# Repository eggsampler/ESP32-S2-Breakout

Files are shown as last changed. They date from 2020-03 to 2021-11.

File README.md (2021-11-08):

# ESP32-S2-Breakout

**May 2021:** New v2 boards [assembled with USB-C connector](https://cdn.discordapp.com/attachments/743434443859034135/847350110374461490/image0.jpg), tested and working well over USB CDC-ACM and DFU programming.

**Feb 2021:** Updated to v2, switched from micro usb to usb-c connector, minor routing changes. PCB ordered, updates to come.

**July 2020:** Board has been [assembled](https://i.imgur.com/Ixv2GHa.jpg), but not fully tested. Currently waiting for ESP-IDF release with full s2 support.

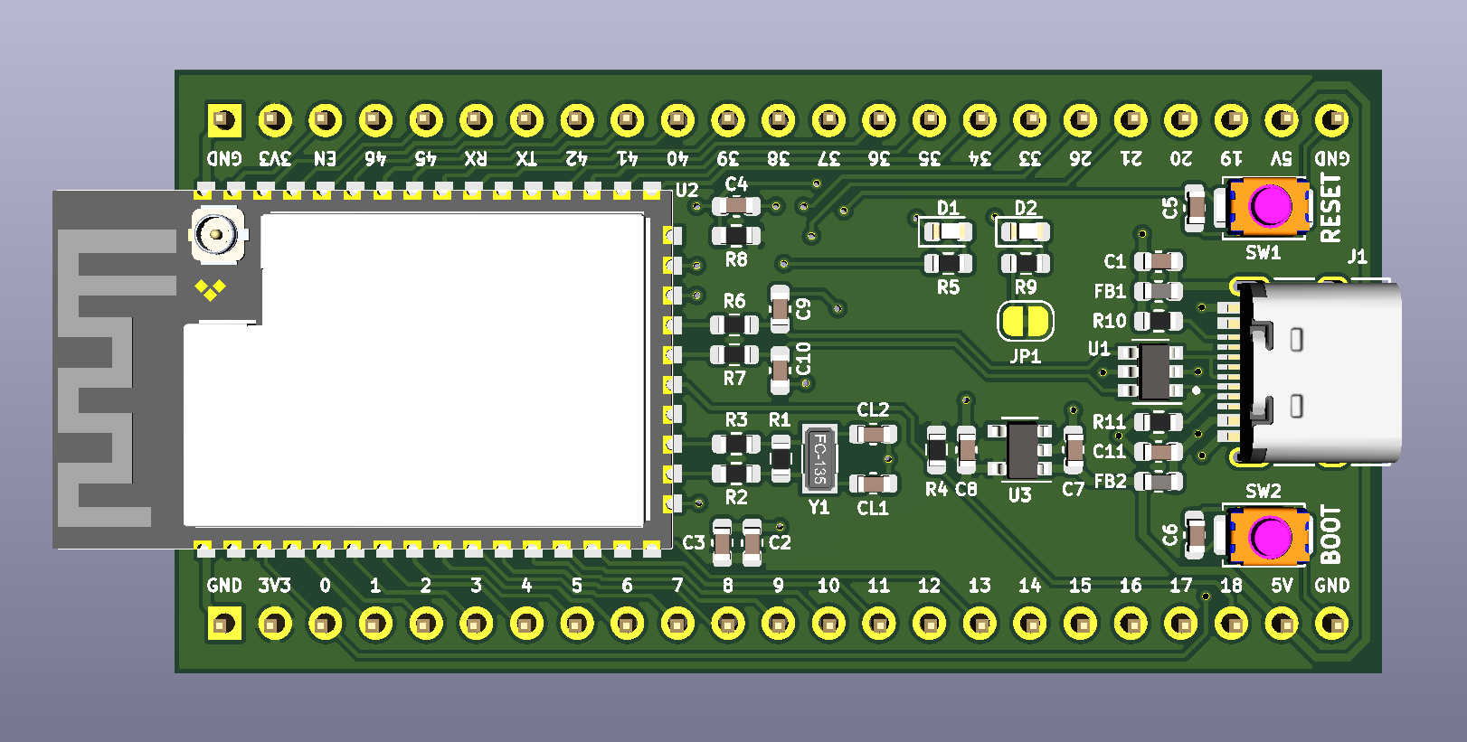
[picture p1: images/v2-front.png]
ESP32-S2-Breakout


This board is a minimal breakout board for the new ESP32-S2-WROOM module from [Espressif](https://www.espressif.com/). It was designed with a few criteria in mind,

- Breakout as many pins as possible, if not all, from the module
- Be relatively easy for a hobbyist to order & assemble
- Use a minimal amount of components

To that end, a few choices were made,

- Designed in [KiCad](https://kicad.org/) to be accessible to most people
- Use as little active components as possible
  - Note, it is definitely possible to use less than is currently laid out and the design will (slowly) be iterated on towards this.
- Using 0603 (imperial) sized passives
  - Ideally the board would be constructed using solder paste, a stencil and either some form of reflow oven or hot plate (even a [skillet on a stove](https://www.sparkfun.com/tutorials/59) is fine)
- To have the boards cheaply manufactured by most turn-key pcb fab houses,
  - Power traces should be at least 12 mil
  - Signal traces should be at least 8 mil
  - Vias should be 0.3mm drill size with a 0.6mm pad size
- No LGA parts, and ideally no QFN parts

## Initial Design

The initial design was taken from the [ESP32-S2-WROOM & ESP32-S2-WROOM-I Datasheet](https://www.espressif.com/sites/default/files/documentation/esp32-s2-wroom_esp32-s2-wroom-i_datasheet_en.pdf) (v0.5) section *6. Peripheral Schematics* Figure 5.

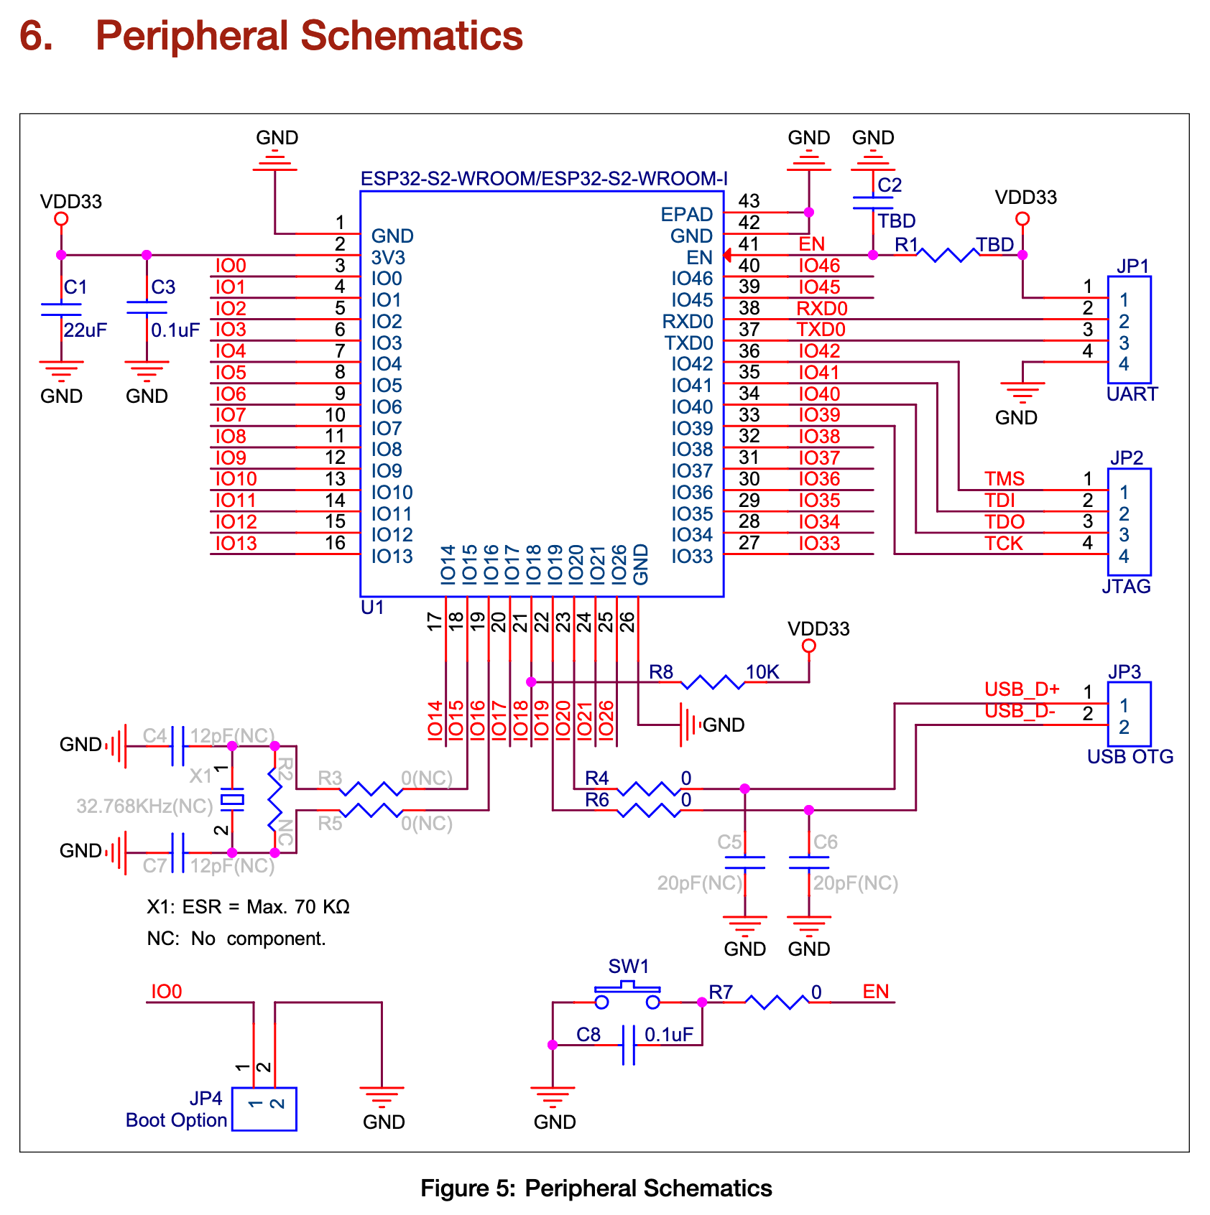
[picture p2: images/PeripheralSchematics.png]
Peripheral Schematics


A few changes were made from this schematic.

- The USB data lines were directed to a USB-C connector
- 22 ohm termination resistors are used on the USB data lines, along with including the 20pF caps
- No 0 resistor was used on the EN reset switch, just tied directly to the EN pin
- A switch was also used on IO0 for the boot mode, instead of a connector/header
- No separate connectors for UART/JTAG, all pins were broken out to 2.54mm/0.1" headers

## Component Selection

### 1. 3v3 Regulator

A regulator which has high efficiencies (ie, low ground/quiescent current) is needed to get the best out of powering the device from higher voltages. The XC6220 has a hysterisis mode called "Green Operation" where the supply current current is much lower when the load current is below 2mA. The v1 of this board will also be a bit of a test for this regulator to see how it handles higher loads for wifi, and lower loads for sleep modes.

### 2. 32.768 KHz Crystal

A few resources were useful when researching crystal and component choices.

1. https://en.wikipedia.org/wiki/Pierce_oscillator
2. http://ww1.microchip.com/downloads/en/AppNotes/00943A.pdf
3. http://www.crystek.com/documents/appnotes/Pierce-GateIntroduction.pdf
4. http://www.st.com/internet/com/TECHNICAL_RESOURCES/TECHNICAL_LITERATURE/APPLICATION_NOTE/CD00221665.pdf

A cheap crystal FC-135 with a max ESR of 70kOhms was used which fits on the KiCad 3215 pad. A few passive values will need to be tested for v1 to determine if they're even necessary.

### 3. Switches / Connectors

The switches and connectors were chosen because they had footprints already in the KiCad library and are relatively accessible from most vendors.

### 4. USB ESD Protection

A USBLC6-2SC6 was chosen for ESD protection of the USB power and data lines. This part was already available in KiCad and at a few distributors. An input capacitor was used fort this part, along with a ferrite bead before the 5v bus.

Another ferrite bead and capacitor was used between the shield and the ground. Probably not strictly necessary.

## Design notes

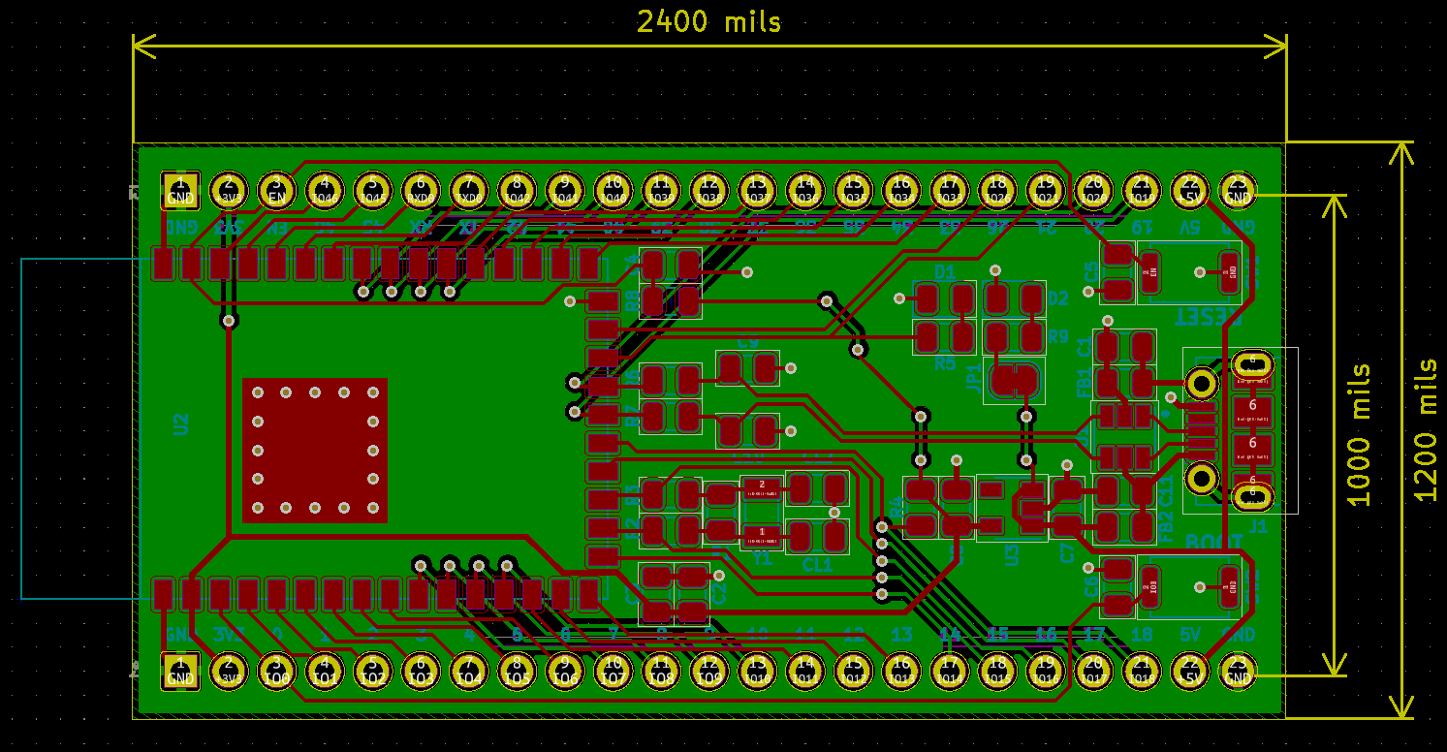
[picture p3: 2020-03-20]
images/v1-pcb.PNG

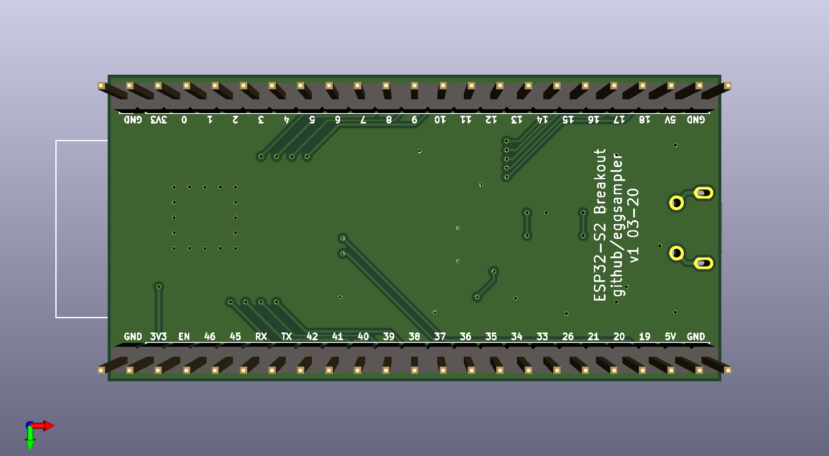
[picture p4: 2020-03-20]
images/v1-back.png

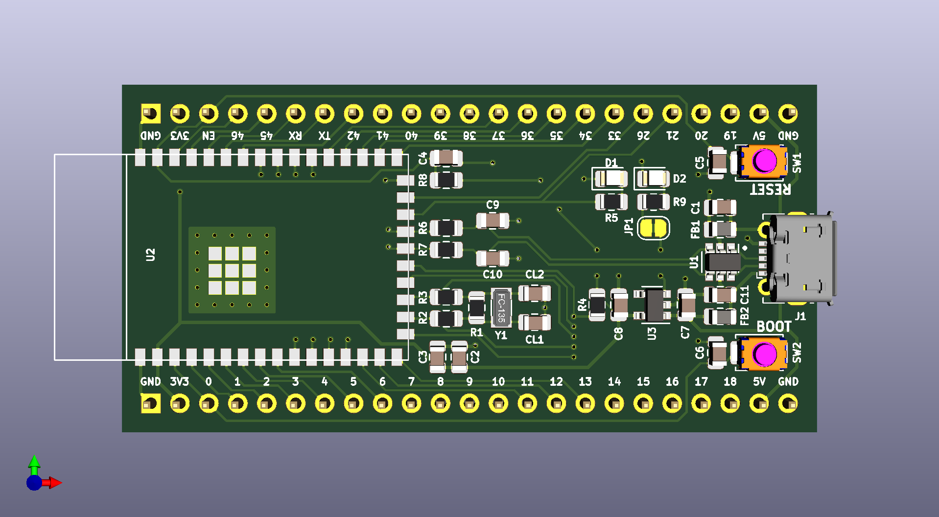
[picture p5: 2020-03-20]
images/v1-front.png

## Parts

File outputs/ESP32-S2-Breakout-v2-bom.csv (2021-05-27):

Qty | Reference(s) | Value | Footprint | LCSC
6 | C1, C3, C4, C5, C6, C11 | 0.1u X7R 50V | C_0603_1608Metric | C14663
1 | C2 | 22u X5R 10V | C_0603_1608Metric | C59461
1 | C7 | 10u X5R 16V | C_0603_1608Metric | C19702
1 | C8 | 4.7u X5R 25V | C_0603_1608Metric | C19666
4 | C9, C10, CL1, CL2 | 20p C0G 50V | C_0603_1608Metric | C1648
1 | D1 | LED 2.8V 5mA Red | LED_0603_1608Metric | C2286
1 | D2 | LED 2.8V 5mA Green | LED_0603_1608Metric | C72043
2 | FB1, FB2 | >1A | L_0603_1608Metric | C85831
1 | J1 | USB_C_Receptacle_USB2.0 | HRO_TYPE-C-31-M-12 | C165948
1 | R1 | N/C | R_0603_1608Metric | -
2 | R2, R3 | 0r | R_0603_1608Metric | C21189
2 | R4, R8 | 10k 5% | R_0603_1608Metric | C25804
2 | R5, R9 | 100r 1% | R_0603_1608Metric | C22775
2 | R6, R7 | 22r 1% | R_0603_1608Metric | C23345
2 | R10, R11 | 5.1k 5% | R_0603_1608Metric | C23186
1 | SW1 | Reset | Alps_SKRK | C115357
1 | SW2 | Boot | Alps_SKRK | C115357
1 | U1 | USBLC6-2SC6 | SOT-23-6 | C558442
1 | U2 | ESP32-S2-WROVER | ESP32-S2-WROVER | C701327
1 | U3 | XC6220B331MR | SOT-23-5 | C86534
1 | Y1 | 32.768KHz 12.5pF 70kR | Crystal_SMD_3215 | C32346

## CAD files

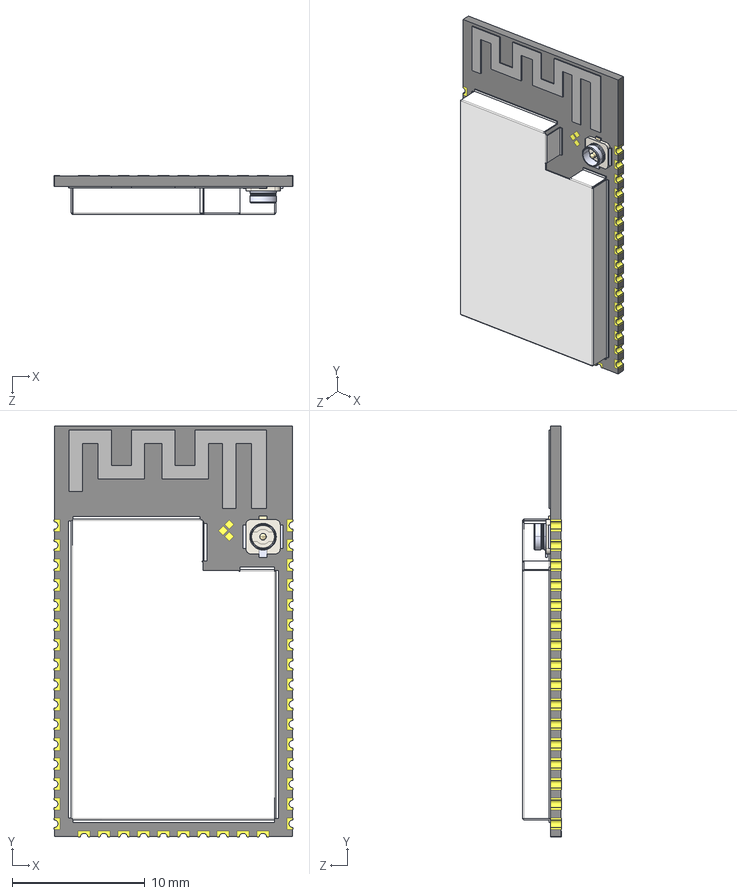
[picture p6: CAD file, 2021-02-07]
ESP32-S2-Breakout/3d/ESP32-S2-WROVER.STEP
18.0 x 31.0 x 2.91 mm

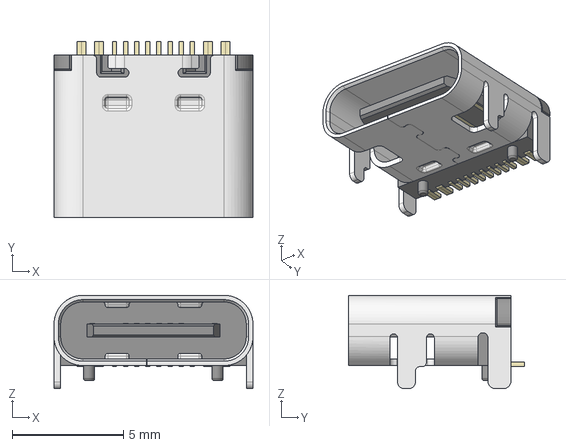
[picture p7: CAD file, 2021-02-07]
ESP32-S2-Breakout/3d/HRO_TYPE-C-31-M-12.step
8.95 x 7.90 x 4.20 mm

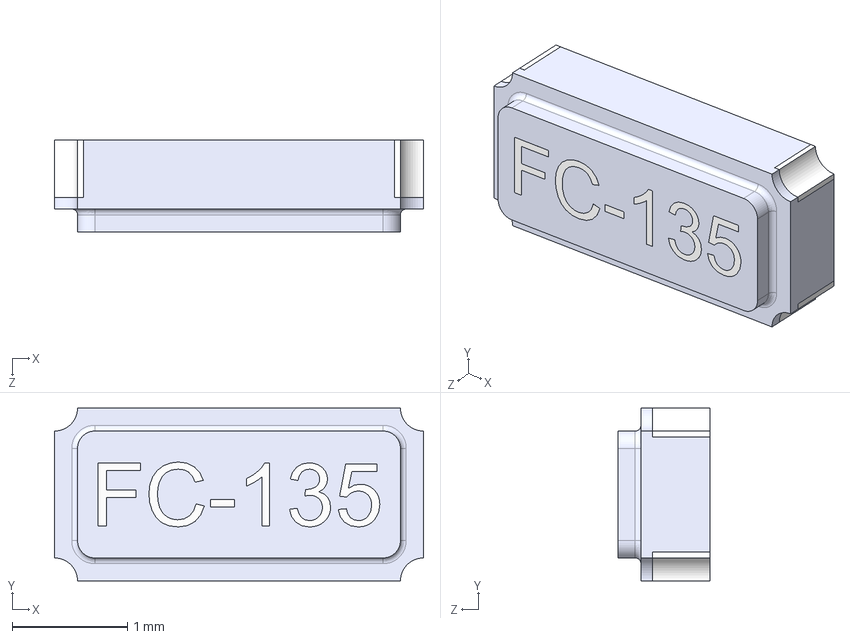
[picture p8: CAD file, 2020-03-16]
ESP32-S2-Breakout/3d/FC-135.STEP
3.20 x 1.50 x 0.8 mm
Pin 2
Pin 1
Tekst Inlay

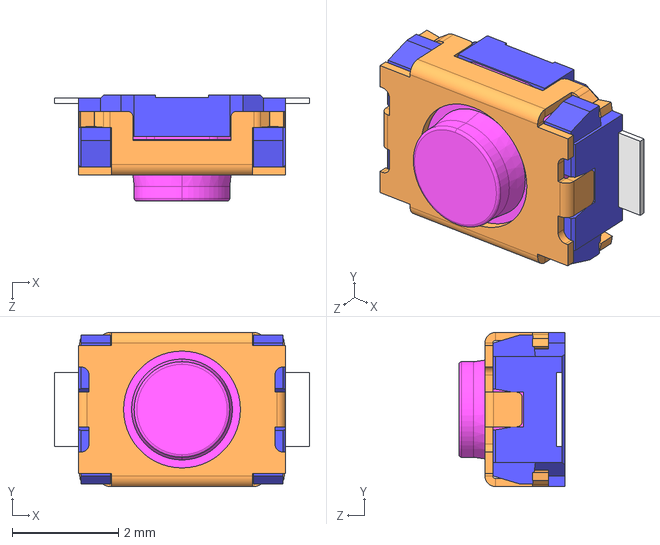
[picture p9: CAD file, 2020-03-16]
ESP32-S2-Breakout/3d/SKRKAH.STEP
4.80 x 2.90 x 2.00 mm

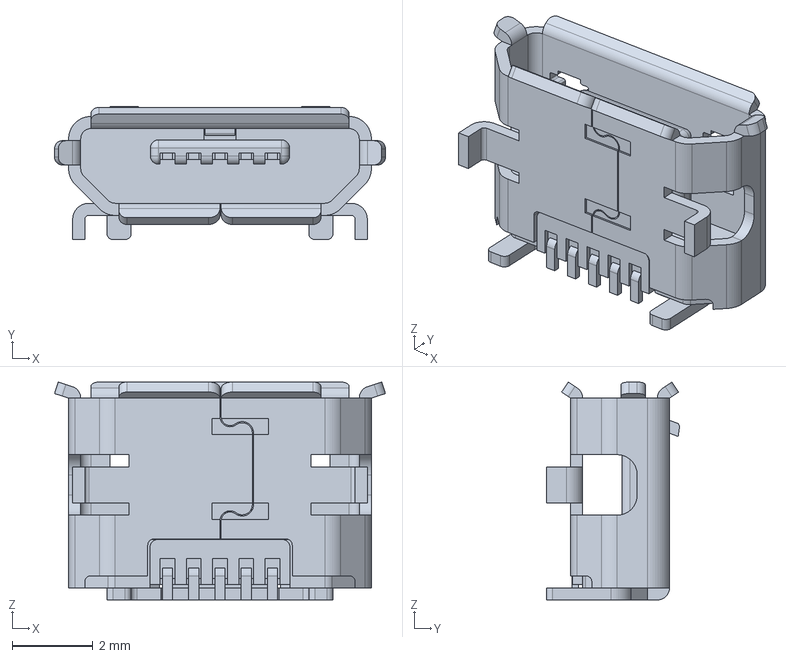
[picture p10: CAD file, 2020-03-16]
ESP32-S2-Breakout/3d/1050170001.stp
8.20 x 3.30 x 5.40 mm

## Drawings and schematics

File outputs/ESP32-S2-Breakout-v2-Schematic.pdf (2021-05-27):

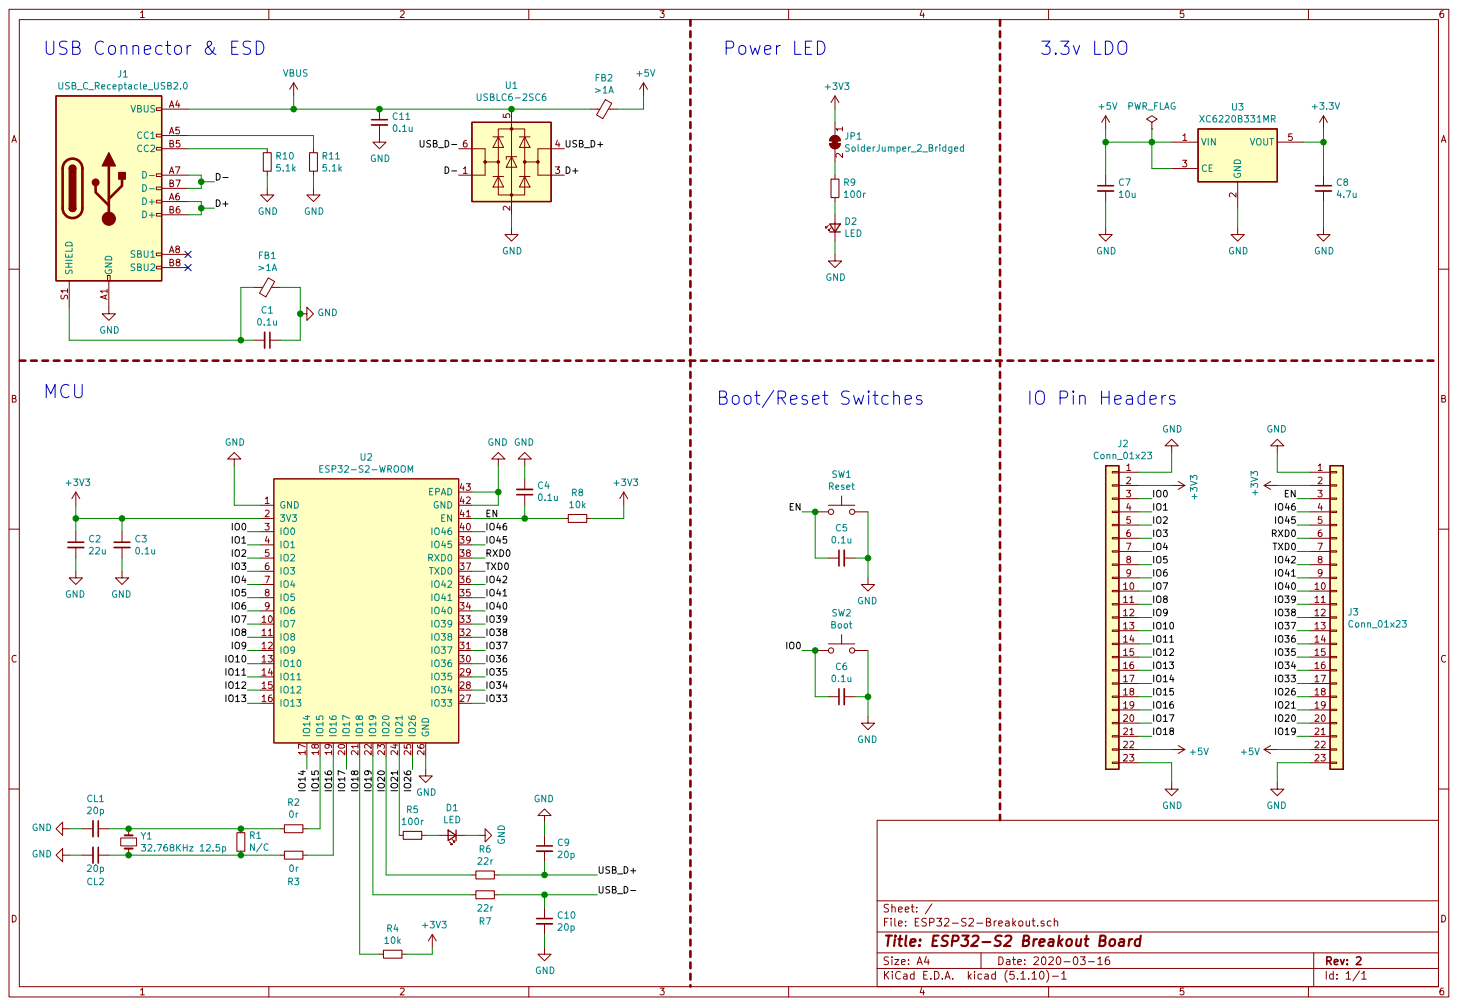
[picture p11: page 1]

File: ESP32-S2-Breakout.sch Sheet: /
Id: 1/1 Title: ESP32-S2 Breakout Board

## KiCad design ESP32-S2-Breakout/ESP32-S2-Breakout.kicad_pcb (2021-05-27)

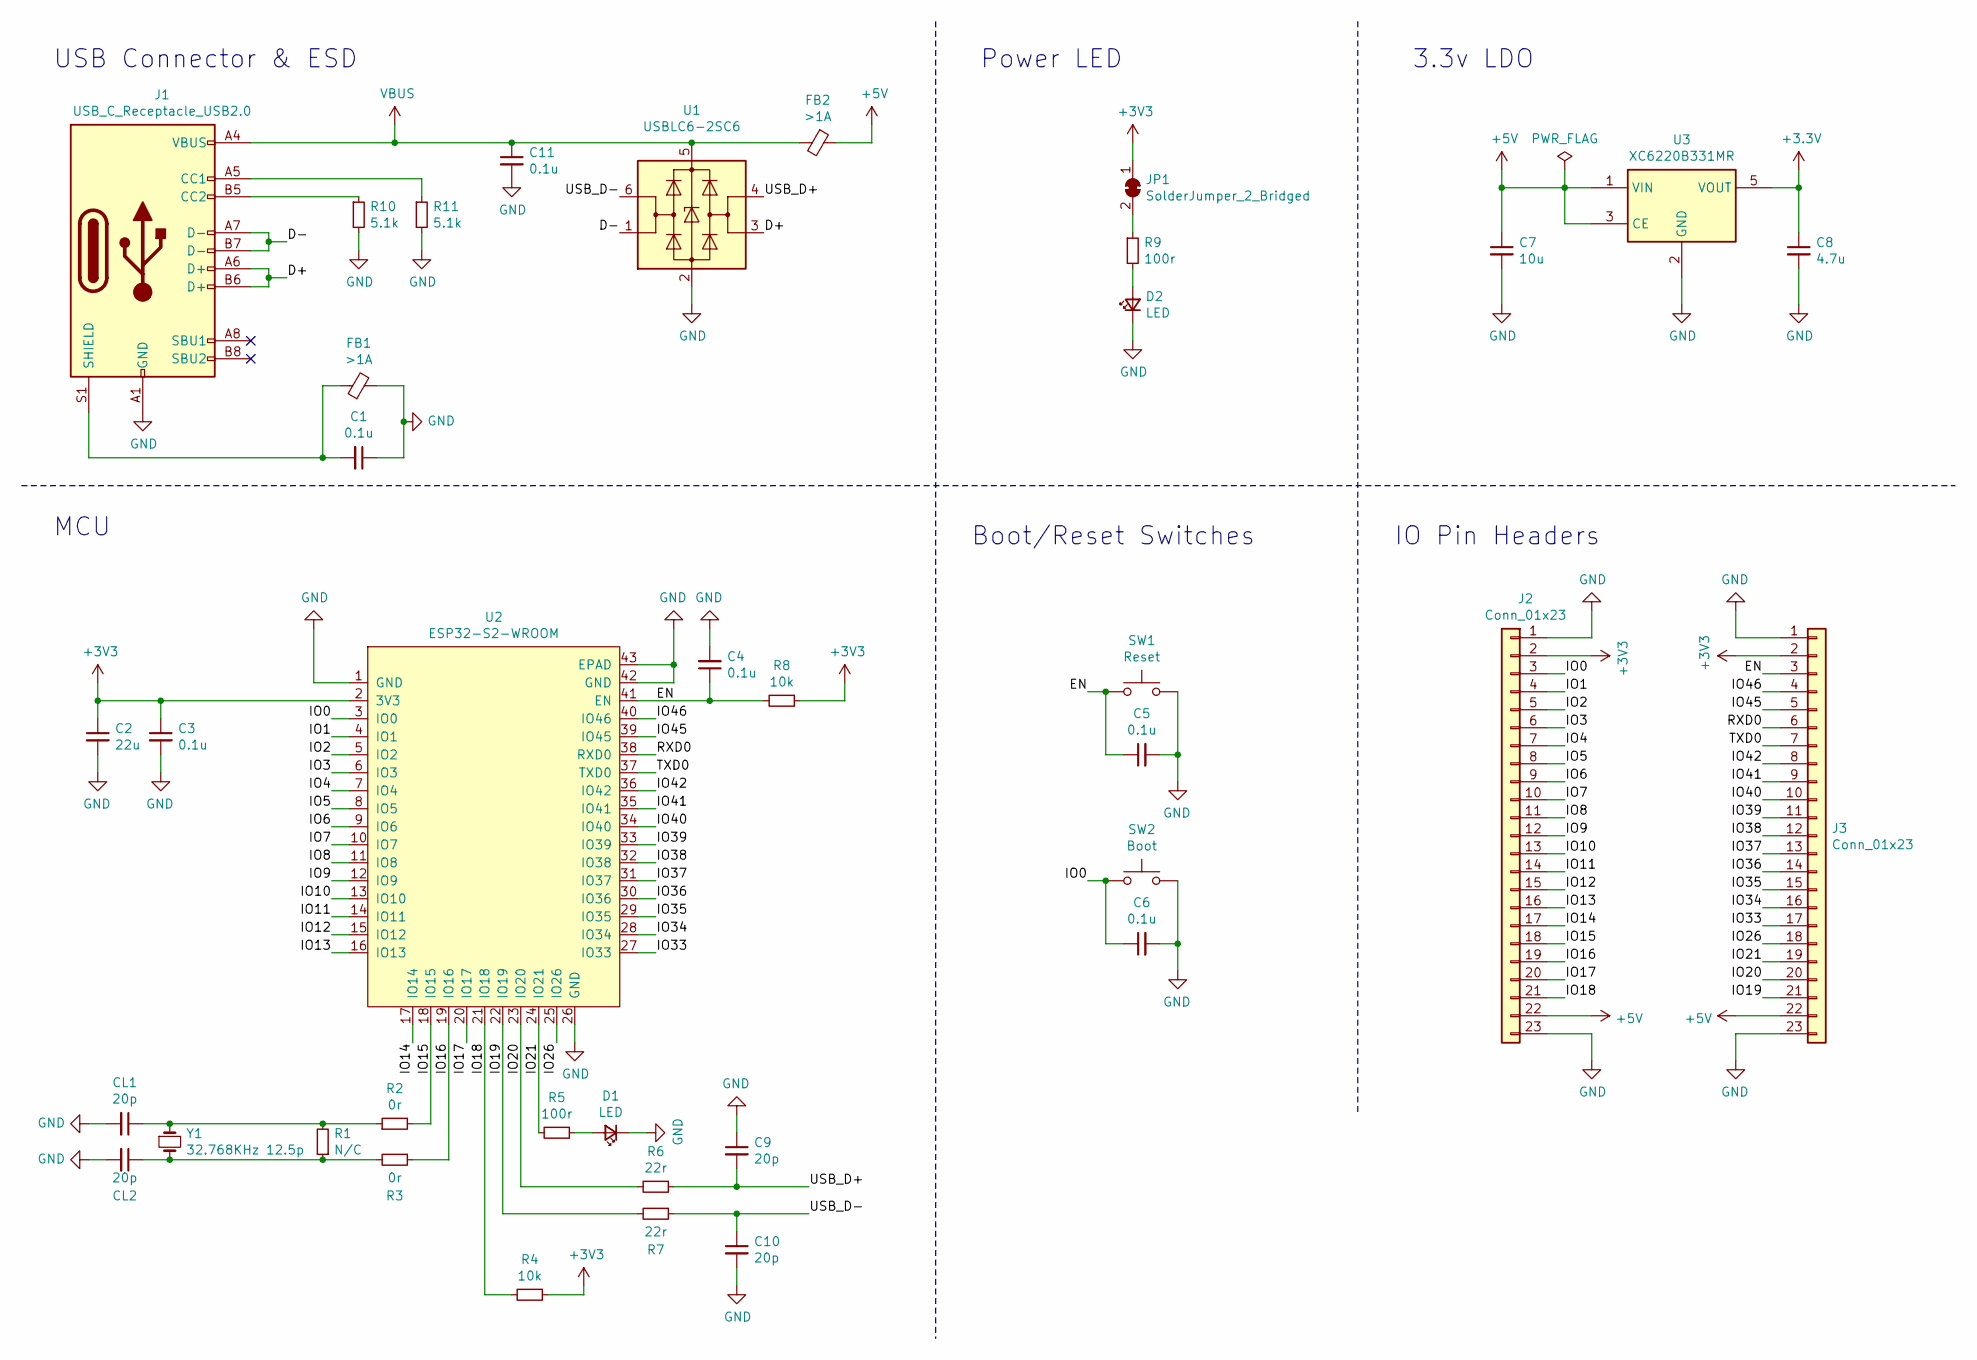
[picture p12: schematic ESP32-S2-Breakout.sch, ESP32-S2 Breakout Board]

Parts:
C1, C3, C4, C5, C6, C11: 0.1u; C_0603_1608Metric; LCSC C14663
C2: 22u; C_0603_1608Metric; LCSC C84419
C7: 10u; C_0603_1608Metric; LCSC C90058
C8: 4.7u; C_0603_1608Metric; LCSC C69335
C9, C10: 20p; C_0603_1608Metric; LCSC C1648
CL1, CL2: 20p; C_0603_1608Metric; LCSC C1648
D1: LED; LED_0603_1608Metric; LCSC C205443
D2: LED; LED_0603_1608Metric; LCSC C205445
FB1, FB2: >1A; L_0603_1608Metric; LCSC C24821
J1: USB_C_Receptacle_USB2.0; USB_C_Receptacle_HRO_TYPE-C-31-M-12; LCSC C165948
J2, J3: Conn_01x23; PinHeader_1x23_P2.54mm_Vertical
JP1: SolderJumper_2_Bridged; SolderJumper-2_P1.3mm_Bridged_RoundedPad1.0x1.5mm
R1: N/C; R_0603_1608Metric
R2, R3: 0r; R_0603_1608Metric; LCSC C21189
R4, R8: 10k; R_0603_1608Metric; LCSC C99198
R5, R9: 100r; R_0603_1608Metric; LCSC C22775
R6, R7: 22r; R_0603_1608Metric; LCSC C23345
R10, R11: 5.1k; R_0603_1608Metric; LCSC C163928
SW1: Reset; Alps_SKRK; LCSC C115357
SW2: Boot; Alps_SKRK; LCSC C115357
U1: USBLC6-2SC6; SOT-23-6; LCSC C7519
U2: ESP32-S2-WROOM; LCSC C701327
U3: XC6220B331MR; SOT-23-5; LCSC C86534
Y1: 32.768KHz 12.5p; Crystal_SMD_3215-2Pin_3.2x1.5mm; LCSC C271654

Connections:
+5V: C7.1, FB2.1, J2.22, J3.22, U3.1 (VIN), U3.3 (CE)
/D+: J1.A6 (D+), J1.B6 (D+), U1.3 (I/O2)
/D-: J1.A7 (D-), J1.B7 (D-), U1.1 (I/O1)
/EN: C4.1, C5.1, J3.3, R8.2, SW1.2, U2.41 (EN)
/IO0: C6.1, J2.3, SW2.2, U2.3 (IO0)
/IO1: J2.4, U2.4 (IO1)
/IO2: J2.5, U2.5 (IO2)
/IO3: J2.6, U2.6 (IO3)
/IO4: J2.7, U2.7 (IO4)
/IO5: J2.8, U2.8 (IO5)
/IO6: J2.9, U2.9 (IO6)
/IO7: J2.10, U2.10 (IO7)
/IO8: J2.11, U2.11 (IO8)
/IO9: J2.12, U2.12 (IO9)
/IO10: J2.13, U2.13 (IO10)
/IO11: J2.14, U2.14 (IO11)
/IO12: J2.15, U2.15 (IO12)
/IO13: J2.16, U2.16 (IO13)
/IO14: J2.17, U2.17 (IO14)
/IO15: J2.18, R2.2, U2.18 (IO15)
/IO16: J2.19, R3.1, U2.19 (IO16)
/IO17: J2.20, U2.20 (IO17)
/IO18: J2.21, R4.2, U2.21 (IO18)
/IO19: J3.21, R7.2, U2.22 (IO19)
/IO20: J3.20, R6.2, U2.23 (IO20)
/IO21: J3.19, R5.2, U2.24 (IO21)
/IO26: J3.18, U2.25 (IO26)
/IO33: J3.17, U2.27 (IO33)
/IO34: J3.16, U2.28 (IO34)
/IO35: J3.15, U2.29 (IO35)
/IO36: J3.14, U2.30 (IO36)
/IO37: J3.13, U2.31 (IO37)
/IO38: J3.12, U2.32 (IO38)
/IO39: J3.11, U2.33 (IO39)
/IO40: J3.10, U2.34 (IO40)
/IO41: J3.9, U2.35 (IO41)
/IO42: J3.8, U2.36 (IO42)
/IO45: J3.5, U2.39 (IO45)
/IO46: J3.4, U2.40 (IO46)
/RXD0: J3.6, U2.38 (RXD0)
/TXD0: J3.7, U2.37 (TXD0)
/USB_D+: C9.2, R6.1, U1.4 (I/O2)
/USB_D-: C10.1, R7.1, U1.6 (I/O1)
GND: C1.1, C2.2, C3.2, C4.2, C5.2, C6.2, C7.2, C8.2, C9.1, C10.2, C11.2, CL1.2, CL2.2, D1.1 (K), D2.1 (K), FB1.2, J1.A1 (GND), J1.A12 (GND), J1.B1 (GND), J1.B12 (GND), J2.1, J2.23, J3.1, J3.23, R10.2, R11.2, SW1.1, SW2.1, U1.2 (GND), U2.1 (GND), U2.26 (GND), U2.42 (GND), U2.43 (EPAD), U3.2 (GND)
unnamed: C1.2, FB1.1, J1.S1 (SHIELD)
unnamed: CL1.1, R1.2, R2.1, Y1.1
unnamed: CL2.1, R1.1, R3.2, Y1.2
unnamed: D1.2 (A), R5.1
unnamed: D2.2 (A), R9.2
unnamed: J1.A5 (CC1), R11.1
unnamed: J1.B5 (CC2), R10.1
unnamed: JP1.2 (B), R9.1
VBUS: C11.1, FB2.2, J1.A4 (VBUS), J1.A9 (VBUS), J1.B4 (VBUS), J1.B9 (VBUS), U1.5 (VBUS)

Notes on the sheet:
USB Connector & ESD
Power LED
3.3v LDO
MCU
Boot/Reset Switches
IO Pin Headers

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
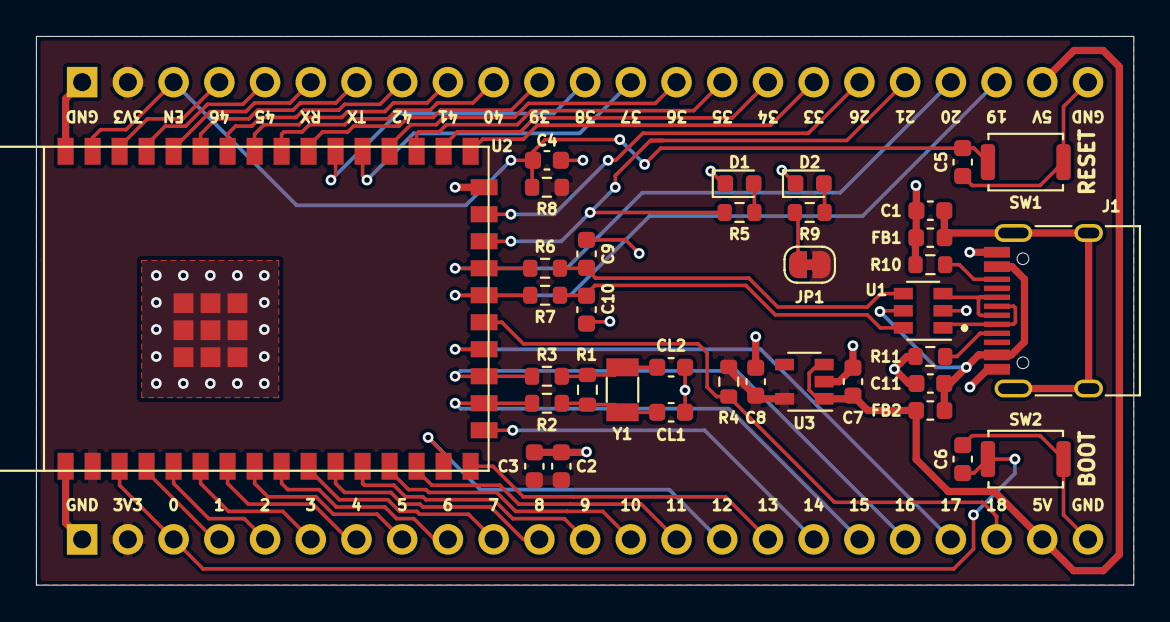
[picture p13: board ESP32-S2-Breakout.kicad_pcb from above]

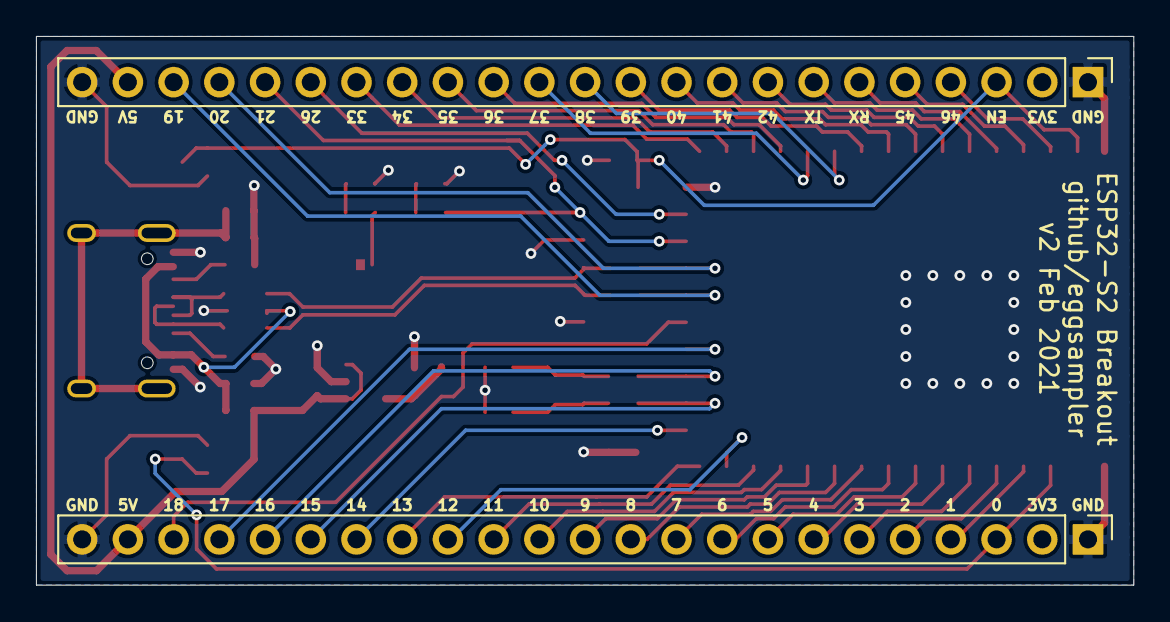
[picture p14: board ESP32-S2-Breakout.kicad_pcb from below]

Board: 2 copper layers, 61.0 x 30.5 mm, 38 parts (2 on the bottom side), 54 nets.

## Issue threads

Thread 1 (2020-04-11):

External crystal 32kHz

fabiuz7, 2020-04-11:
Hi Isaac,
thanks for sharing your breakout board.
I was wondering why you inserted an external 32kHz crystal when you should be able to use the internal 31.25kHz derived from 8MHz clock. Is it to improve the accuracy of the timer?

eggsampler, 2020-04-11:
Hi, thanks for the question!

Essentially yes, internal RC oscillators for most MCU's are not super accurate.

My experience with the original ESP32 and using the internal oscillator for ULP/RTC deep sleep and other timing functions showed that it drifted up to a few seconds every minute. The RC oscillators seem to vary quite a bit with temperature and also between production runs. This is probably fine for most things, but when you have deployed devices operating for weeks to months at a time remotely, the drift is very noticeable.

Some of my use cases for the new ESP32-S2 involve utilising the new ULP co-processor. With an actual RISC core instead of the older 16bit state machine this should give a lot more functionality without needing to wake up the main core for power savings. So more accurate timings using an accurate crystal that's measured like 10 to 20 PPM as opposed to a few percent makes sense.

fabiuz7, 2020-04-11:
Thanks for the clear explanation! I probably will rely on the internal clock saving few components, my application will need to sleep for some minutes between a measure and the next one, drifting off a few seconds doesn't really matter.

eggsampler, 2020-08-24:
Hi,

I have not properly tested this board yet post assembly as I am waiting for the 4.2 release of the IDF with full support for the RISC & state machine ULP. See: https://www.esp32.com/viewtopic.php?f=10&t=14532

The crystal I chose was this one: https://au.mouser.com/ProductDetail/732-FC-13532.76KAA0
Had an ESR of less than 70kR as per the datasheet, with a load capacitance of 12.5pF

I didn't use any biasing resistors (populated the series resistors with 0 and left the bias parallel resistor empty).

I only had 12pF C0G capacitors on hand, realistically I believe I should have populated these with at least 15pF to 22pF
https://www.nxp.com/docs/en/supporting-information/R_10077.pdf

Hope this helps!

fabiuz7, 2020-10-04:
I can confirm that it works with 18pf.

[Here](https://easyeda.com/fabiano.riccardi/esp32-s2-breakout-board) the board I'm working on.

mrWheel, 2024-02-13:
Will this board “work” without the external crystal circuitry as the chip already has a 32kHZ crystal on board?

Are you still developing this board?

eggsampler, 2024-02-13:
You will only need an 32.768khz crystal if you want an accurate clock for RTC. Otherwise it will use an internal RC oscillator tuned from the 40MHz crystal if I recall.

Have used a couple of these for small projects but nothing serious. Don't plan on doing much with it.

Closed 2020-10-04.

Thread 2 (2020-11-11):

Do you already have a free USB ID registered for your device (For porting Circuitpython to it)

expandme-tech, 2020-11-11:
https://github.com/adafruit/circuitpython/issues/3414#issuecomment-724896324

https://github.com/skieast/circuitpython/tree/main-copy/ports/esp32s2/boards

Rudolf

eggsampler, 2021-05-26:
This is not something I plan on doing as it is just a one-off general purpose dev board and not a specific project, sorry.

Closed 2021-05-26.

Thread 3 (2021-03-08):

Was the test of the crystal successful?

MangoIV, 2021-03-08:
Hi! I'm currently trying to design a PCB using the esp32-s2 wroom and am wondering whether you already have a reference on which passives work with the oscillator. I'm especially interested in the values of the 3 resistors.
Thanks in advance.

eggsampler, 2021-03-08:
Hi,

I ended up using no resistors apart from a zero ohm on the series one. With standard crystal resistors there didn't seem to be any real need to limit the drive current or have these resistors at all.

Happy to be proven wrong, but it worked fine without it.

Closed 2021-03-08.

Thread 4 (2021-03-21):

Is it possible to use the 32kHz crystal with the wires?

andershedberg, 2021-03-21:
Hi, juts wondering if the 32KHz crystal has been tested and works with the layout? When I worked with STM controllers they are very sensitive to the wiring of the 32 kHz x-tal requiring grounded guard rails etc.

Any other news if this board is working well?

eggsampler, 2021-05-27:
Hi, late reply I know, sorry!

I've just had some of the v2 boards assembled and all tests well, I've included the BOM file I used for ordering from JLCPCB which includes the specific LCSC product code for components I have used. The crystal seems fine so far, along with some series 0 ohm resistors (which probably aren't necessary, I just included them for a footprint if it needed to be tuned), no parallel resistor, and the 20f caps. Have not put it on a scope to check the waveform, but I will look at doing that soon.

There are a few boards spare, so if you want to email me via esp32 at eggsampler dot com I'd be happy to mail you a board free to try yourself.

andershedberg, 2021-05-31:
Great! I actually modified your board to fit a touch-application and will assembly it now to see if it worked! If not, I might pick you up on your kind offer!

Closed 2021-05-31.

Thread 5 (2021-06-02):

Which USB cable was it tested with?

andershedberg, 2021-06-02:
Hi, having a bit of a problem with my version I wonder what kind of USB connection this was tested with?

If I use a USB A to USB C cable I get power on the board. ( but no connection )
If I use a USB C to USB C cable I do not get power to the board. ( and no connection of course )

It seems I got the wrong USB C connector on my board, they look all the same, but there are minor differences, so I will look into that to see if it really has a connection even though it looks like that.

eggsampler, 2021-06-02:
This is the connector I used: https://lcsc.com/product-detail/USB-Connectors_Korean-Hroparts-Elec-TYPE-C-31-M-12_C165948.html

Which one did you use?

andershedberg, 2021-06-02:
This one, as I thought it was faster to ship from the US/Mouser ( Don't, the ESPRESSIF Modules are for US only and can't be exported to Europe for some paperwork... so I got those from a friend. ). USB - Unfortunately the front metal pins are wider than the original and there is no drawing in the datasheet to tell. https://www.jae.com/direct/topics/topics_file_download/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

andershedberg, 2021-06-04:
Sorry, back to the question - as I experience problems with a pure USB C to USB C cable. Did you try it with that and the board got power? That only happens with my USB C to USB A cable.

eggsampler, 2021-07-01:
I've just gone through and tested with a USB-C to USB-C macbook pro cable and it powered on and worked from both the charger, and uploaded code fine from the macbook. Did you end up having any luck?

andershedberg, 2021-07-02:
Great news! Even though I could not get it to work :-/

I cut a USB A mouse-cable and soldered it directly to the ESP32 side of things and then it worked and could be flashed etc. I could not get the USB C to even deliver power to it so something was not right from my HP and Acer laptops. I did not spend more time with it, as it might have been my soldering, my a bit modified board layout, wrong component rotation or the USB C board connector which I thought were standardized but I ended up with the wrong one ( a bit too long metal case legs, and there are no measurments for that in the datasheets, really strange ). I ended up doing your older micro-USB design and will mount it tomorrow. If I get more time I might try to mount an extra USB-C board as I have now got some better soldering equipment as well and know that it should work :-)

Closed 2021-07-02.

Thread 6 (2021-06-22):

Most compatible board definition in Arduino?

john--, 2021-06-22:
Hi there,

Board works great. Thanks so much for this. I was just curious if you use Arduino for flashing sketches, and if so, which definition do you use? "Adafruit Feather ESP32-S2 (no PSRAM)" seems to work, but I've been struggling to get i2c working on pins 8/9 (even with the appropriate pull-ups), and can't really figure out what I could be doing wrong.

eggsampler, 2021-07-01:
Hi,

I tend to use PlatformIO, but if you use the latest development version of the esp32-arduino and use the "ESP32S2 Dev Module" board, that should be the most compatible.

Closed 2021-07-01.

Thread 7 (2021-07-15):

PDF schematic

ilium007, 2021-07-15:
Hi - any chances of a PDF version of the schematic? Cheers.

ilium007, 2021-07-15:
Sorry - just found it in the outputs folder.

eggsampler, 2021-07-15:
No problem! 👍

Closed 2021-07-15.

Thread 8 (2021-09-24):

What is the value of R1?

crgarcia12, 2021-09-24:
What should be the value of R1?
I see it is marked as N/C, and I am not sure if that resistor should be there at all, or if it has to be ommited

Thanks!

eggsampler, 2021-09-25:
The crystal and associated caps and resistors form part of a Pierce Oscillator https://en.wikipedia.org/wiki/Pierce_oscillator

As seen in the ESP32 S2 Hardware Design Guidelines section '2.4.2 RTC (optional)' https://www.espressif.com/sites/default/files/documentation/esp32-s2_hardware_design_guidelines_en.pdf

Generally speaking you won't need to populate it, or even add a footprint for the series or parallel resistors there at all.

crgarcia12, 2021-09-30:
thanks a lot for answering @eggsampler!!

Closed 2021-10-10.

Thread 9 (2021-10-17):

C6 makes the board boot into DFU mode when not powered for a while

andershedberg, 2021-10-17:
Hi, and a big thanks for the design!

I have now build a few (with USB micro connector instead of the USB-C ) and noticed that all boards when not powered for a while, boots into the DFU mode (i.e where it expects code to be downloaded to it) as if the BOOT button is pressed. The same effect happens if the board is removed from USB power, boot button is pressed to empty the C6 charge, releasing the boot button and then connecting the board to USB (power) again.

Removing the C6 100nF capacitor solves the problem and the board boots into the flashed program. as expected.

eggsampler, 2021-10-18:
No problem at all, I'm glad to hear it!

You make a very good point actually and in hindsight that is definitely a mistake on my part. I normally add a little capacitor with buttons like these to act as a bit of cheap and easy hardware debouncing. My guess is it's something to do with a combination of the capacitor retaining charge and the state of this IO pin on boot.

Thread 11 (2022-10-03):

Why is the shield connected using a ferrite and capacitor?

crgarcia12, 2022-10-03:
Thanks a lot for sharing this design! Super useful!

I never saw the USB Shield connected to GND the way you did it. Could you please help me understand why you did it this way?

I want to mirgrate my ESP32-Wroom-D based board to the S3 (https://github.com/crgarcia12/electronics-homeassistant-lightscontroll).
I read a lot about the USB shield on the internet, but it seems there is no consensus on what to do with it. In my case, I ended up connecting it to GND via a resistor, but in practice it worked with or without the resistor (I'm using an isolated PS)

Thank you!

eggsampler, 2022-10-27:
This is just a filter for the shield connection. It's not based on anything other than observations. They can be entirely omitted and that won't be a problem for a majority, if not all, use cases.

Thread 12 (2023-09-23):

Information about the card

hamzadenizyilmaz, 2023-09-23:
Hello, I produced this card and it came to my hand, since you wrote "N / C" on the card "R1" numbered resistor "N / C", I did not put that resistor on the card, will there be a problem or not?

Thank you good work
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

eggsampler, 2023-09-23:
Hi, this resistor is not necessarily required, depending on the crystal or oscillator that is being used. Chances are you won't have a problem, especially if you're not using any RTC or clock features to even use that crystal in the first place.

https://en.wikipedia.org/wiki/Pierce_oscillator#Biasing_resistor

hamzadenizyilmaz, 2023-09-23:
> Hi, this resistor is not necessarily required, depending on the crystal or oscillator that is being used. Chances are you won't have a problem, especially if you're not using any RTC or clock features to even use that crystal in the first place.
>
> https://en.wikipedia.org/wiki/Pierce_oscillator#Biasing_resistor

Ok, thanks, I won't use RTC or clock features anyway, but I still want to ask, if I want to use these two features, which resistor would be better to put in the middle?

eggsampler, 2023-09-23:
Even if you use those features, you probably won't need any resistor there at all. The footprint is only included just in case there is any problems with the crystal.

If you notice the crystal not starting up properly, or not stabilising, or you have issues and the waveform across the crystal looks weird, you might need to put like a 10 megaohm resistor there. It is extremely unlikely this will happen though.

hamzadenizyilmaz, 2023-09-23:
Hmm I understand sir, thank you, I would like to ask you a few questions in private, sir, can I ask for your e-mail address?

hamzadenizyilmaz, 2023-09-23:
> Even if you use those features, you probably won't need any resistor there at all. The footprint is only included just in case there is any problems with the crystal.
>
> If you notice the crystal not starting up properly, or not stabilising, or you have issues and the waveform across the crystal looks weird, you might need to put like a 10 megaohm resistor there. It is extremely unlikely this will happen though.

Hmm I understand sir, thank you, I would like to ask you a few questions in private, sir, can I ask for your e-mail address?

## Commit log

2020-03-16 Initial hardware commit
    [1050170001.stp, ESP32-S2-Breakout.kicad_pcb, ESP32-S2-Breakout.sch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]
2020-03-16 Schematic for v1
2020-03-16 Gerbers for v1
    [ESP32-S2-Breakout-B_Cu.gbr, ESP32-S2-Breakout-B_Mask.gbr, ESP32-S2-Breakout-B_Paste.gbr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]
2020-03-16 PCB Images for v1
2020-03-16 Add resistor values for 1.8V/2mA LEDs
    [ESP32-S2-Breakout.kicad_pcb, ESP32-S2-Breakout.sch]
2020-03-16 Add USB series termination resistor and bypass capacitor values
    [ESP32-S2-Breakout.kicad_pcb, ESP32-S2-Breakout.sch]
2020-03-16 Add resistor and capacitor values for 32.758kHz crystal
    [ESP32-S2-Breakout.kicad_pcb, ESP32-S2-Breakout.sch]
2020-03-16 Add values for ferrite bead on usb connector
    [ESP32-S2-Breakout.kicad_pcb, ESP32-S2-Breakout.sch]
2020-03-16 Update schematic PDF for new component values
2020-03-16 Update images, add pcb image
2020-03-16 Minor pcb track changes, re-export gerbers and drill files
    [ESP32-S2-Breakout-B_Cu.gbr, ESP32-S2-Breakout-B_Mask.gbr, ESP32-S2-Breakout-B_Paste.gbr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]
2020-03-16 Add 5v and extra gnd pin to pin headers, rearrange pcb
    [ESP32-S2-Breakout-B_Cu.gbr, ESP32-S2-Breakout-B_Mask.gbr, ESP32-S2-Breakout-B_Paste.gbr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]
2020-03-16 Add v1 gerber zip file
2020-03-17 Added copper pour around EPAD
    [ESP32-S2-Breakout-B_Cu.gbr, ESP32-S2-Breakout-B_Mask.gbr, ESP32-S2-Breakout-B_Paste.gbr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]
2020-03-19 Add polarity marker to TVS
    [ESP32-S2-Breakout.kicad_pcb]
2020-03-19 Update gerbers
    [ESP32-S2-Breakout-B_Cu.gbr, ESP32-S2-Breakout-B_Mask.gbr, ESP32-S2-Breakout-B_Paste.gbr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]
2020-03-19 Add peripheral schematics image
2020-03-20 Change all passives from 0603 to 0805 Add capacitor to input pin of USBLC6 Update gerbers and images
    [ESP32-S2-Breakout-B_Cu.gbr, ESP32-S2-Breakout-B_Mask.gbr, ESP32-S2-Breakout-B_Paste.gbr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]
2020-03-20 Update crystal passive values and readme
    [ESP32-S2-Breakout.kicad_pcb, ESP32-S2-Breakout.sch]
2020-07-30 Update README.md
    Add update for assembly and testing
2020-10-19 Update USB TVS
    [ESP32-S2-Breakout-B_Cu.gbr, ESP32-S2-Breakout-B_Mask.gbr, ESP32-S2-Breakout-B_Paste.gbr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]
2021-02-07 Rev 2/v2 update
    [ESP32-S2-Breakout-B_Cu.gbr, ESP32-S2-Breakout-B_Mask.gbr, ESP32-S2-Breakout-B_Paste.gbr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]
2021-05-27 Minor routing updates, include all updated outputs for v2
    [ESP32-S2-Breakout.kicad_pcb]
2021-05-27 Update README
    Include update for newest v2 board
2021-05-27 Add v2 BOM and centroid file
    [ESP32-S2-Breakout-v2-bom.csv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]
2021-11-08 Update README.md
    https://forum.kicad.info/t/warning-avoid-all-links-to-kicad-pcb-org-use-kicad-org/31521
